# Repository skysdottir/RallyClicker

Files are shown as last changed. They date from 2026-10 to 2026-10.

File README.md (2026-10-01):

# A heltec t114-based sequence and time tracker for rally usage
## This is super prototype code, it seems to work but I make no guarantees.

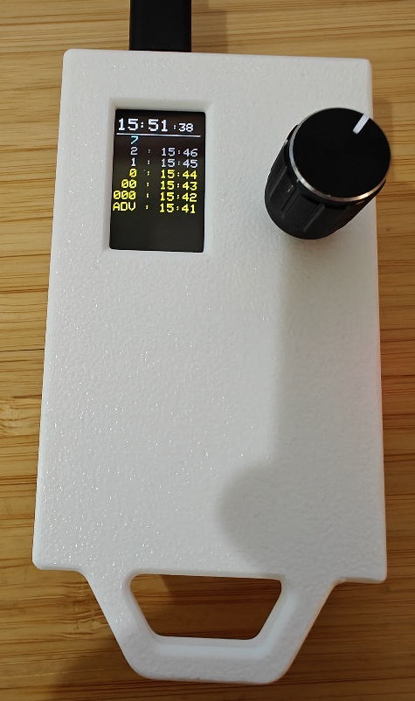
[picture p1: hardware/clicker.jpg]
A little device with a knob and screen. The screen displays time and log entries


## User Guide

The clicker display has two sections: a gps-synced real-time clock at the top and a log of button clicks below.

As is traditional with rally, the number seqence starts with the advance car, then 000, 00, and 0 before reaching sequence number 1. The teal number at the top of the log is the *next* sequence number, clicking will commit it and the current time to the log

When the clicker starts, the clock will be all red Xes and the knob will do nothing- this is normal while waiting for GPS.

Once GPS time is synced, the clock will update to real time (in the configured time zone), and the knob will begin to function:

**Clicking the knob** will record an entry to the log

**Twisting the knob** will scroll up or down the log. Clicking while scrolled down will still record to the top of the log, and scroll back up to the top - no need to worry about messing up the order

**Long-pressing the knob** will enter number-selection mode. The blue *next* number will blink

**While in number-selection-mode** twisting the knob will adjust the *next* number. Clicking or long-pressing the knob will return to log mode but not log an entry.

**Long-pressing the menu button** will enter the menu, for time zone adjustment

**Pressing the menu button again** will exit the menu

**The knob** will navigate and manipulate the menu. Click on an entry to adjust it, click again to back out to navigation.

*Note that this library currently only stores the log in memory - turning it off and then on again wil loose the current log!*

## Hardware needed
- Heltec T114
- Heltec GPS module (for time sync)
- Battery
  - 30mm x 40mm x 8mm
  - 1000mah
- Rotary encoder with click-button (for human input)
  - I used a generic KY-040 dev board
- MTS-101 mini toggle switch

## Wiring diagram

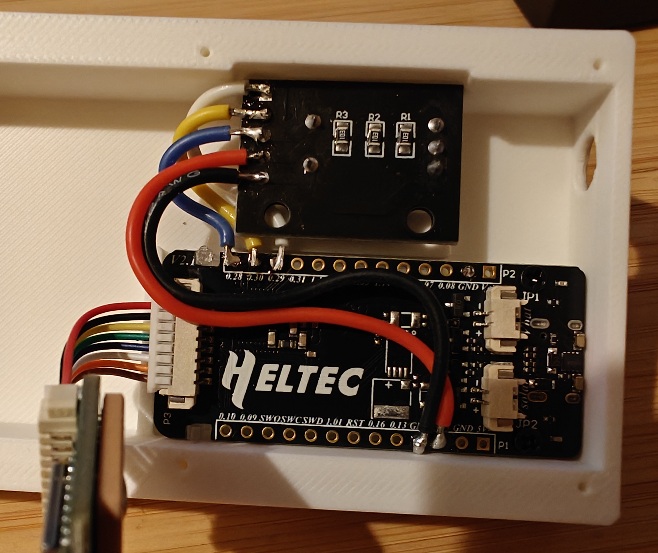
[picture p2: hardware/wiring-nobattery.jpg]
The interior of the device, with wiring displayed. The rotary encoder is connected to the T114


## Pin assignments

- **0.29** Rotary encoder CLK pin
- **0.30** Rotary encoder DT pin
- **0.28** Rotary encoder SW pin
  - (Yes, the IO pins are in this order on the board for some reason)

- **V3.3** Rotary encoder + pin
  - Might also work from Ve3.3, but haven't tried
- **G** Rotary encoder ground pin

## Software process

RallyClicker is a PlatformIO project, developed in VS Code. That'll be by far the easiest way to build, run, and flash the project.

In traditional arduino fashion, everything is mashed into main.cpp.

SPI TFTs are slow and drawing to the screen blocks encoder I/O: minimizing redraws is important.

## Acknowledgements

This project would not exist without the open source community

Graphics, filesystem, and neopixel libraries from Adafruit
Radio library (unused but needed for board) by Jan Gromeš
TinyGPSPlus library by Mikal Hart
AdvancedRotaryEncoder lib by Paul Thomsen 
Time library by Paul Stoffregen
Regexp library by Nick Gammon

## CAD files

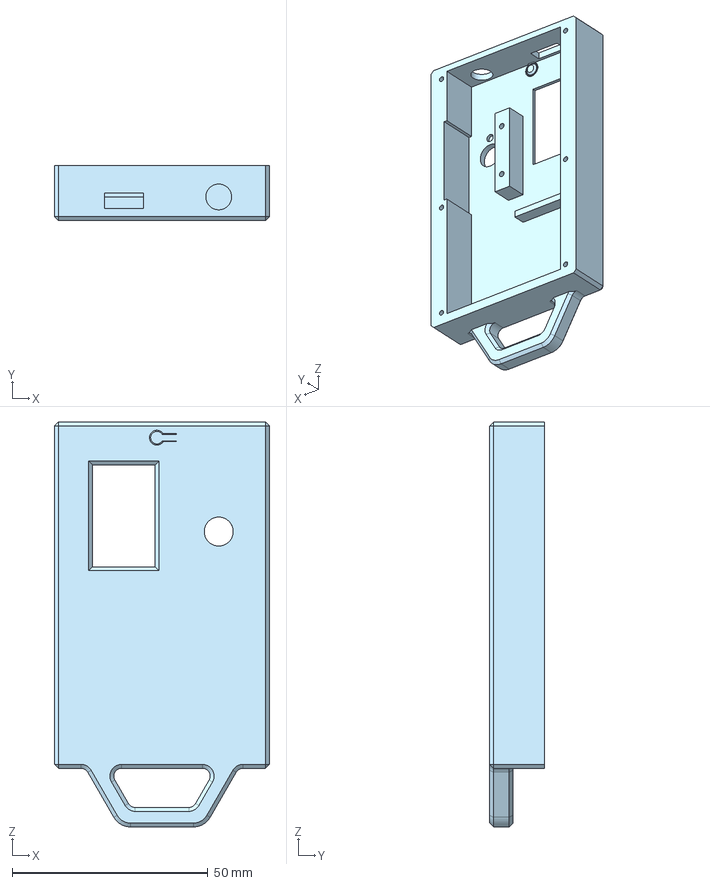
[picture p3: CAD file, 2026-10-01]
hardware/rally clicker - shell.step
55.0 x 14.0 x 103.5 mm

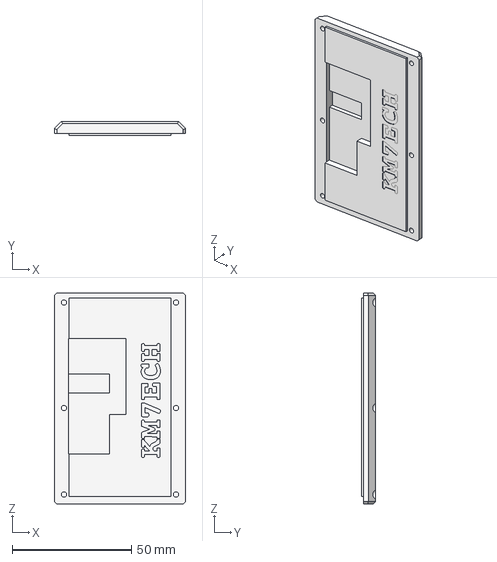
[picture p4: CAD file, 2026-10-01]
hardware/rally clicker - back.step
55.0 x 6.00 x 88.5 mm

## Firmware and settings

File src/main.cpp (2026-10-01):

#include <Adafruit_GFX.h>
#include <Adafruit_ST7789.h>
#include <Adafruit_LittleFS.h>
#include <InternalFileSystem.h>
#include <Arduino.h>
#include <TinyGPSPlus.h>
#include <TimeLib.h>
#include <Regexp.h>
#include <RotaryEncoder.h>

/* ADC */
#define SOC_GPIO_PIN_T114_ADC_EN 6 // P0.06

/* Ext. sensors */
#define SOC_GPIO_PIN_T114_VEXT_EN 21 // P0.21

/* TFT */
#define TFT_WIDTH  135
#define TFT_HEIGHT 240
#define SOC_GPIO_PIN_T114_TFT_MOSI  9 // P1.09
#define SOC_GPIO_PIN_T114_TFT_MISO  11 // P1.11 NC
#define SOC_GPIO_PIN_T114_TFT_SCK   8 // P1.08
#define SOC_GPIO_PIN_T114_TFT_SS    11 // P0.11
#define SOC_GPIO_PIN_T114_TFT_DC    12 // P0.12
#define SOC_GPIO_PIN_T114_TFT_RST   2 // P0.02
#define SOC_GPIO_PIN_T114_TFT_EN    3 // P0.03
#define SOC_GPIO_PIN_T114_TFT_BLGT  15 // P0.15

/* inputs */
#define CLICK_PIN 28
#define SCROLL_DIR_PIN 30
#define SCROLL_TRIGGER_PIN 29
#define MENU_BUTTON_PIN 42

/* GPS PPS pin - gotta get those micros*/
#define GPS_PPS_PIN 36

/* GPS */
#define GPSBAUD 9600

/* Battery status */
#define BATTERY_ADC_ACTIVATE_PIN 6
#define BATTERY_ADC_PIN 4
#define BATTERY_TOTAL_RESIST 490.0
#define BATTERY_LOWER_RESIST 100.0

/* File system */
#define CONFIG_FILE_NAME "/rallyclickconfig.txt"
#define LOG_FILE_NAME "/rallyclicklog.txt"

/* Magic numbers */
#define BUF_SIZE 1024 // An event is never going to have more than 1024 cars, right?

// don't do this
#define TIME_ZONE_COUNT 38
int timezones[] = {-1200, -1100, -1000, -930, -900, -800, -700, -600, -500, -400, -330, -300, -200, -100, 0, 100, 200, 300, 330, 400, 430, 500, 530, 545, 600, 630, 700, 800, 845, 900, 930, 1000, 1030, 1100, 1200, 1245, 1300, 1400};
int timezone = -700;
int time_zone_index = 6;

TinyGPSPlus gps;
Adafruit_ST7789 tft(&SPI1, SOC_GPIO_PIN_T114_TFT_SS, SOC_GPIO_PIN_T114_TFT_DC, SOC_GPIO_PIN_T114_TFT_RST);
RotaryEncoder encoder(SCROLL_TRIGGER_PIN, SCROLL_DIR_PIN, CLICK_PIN);

// GPS ISR flags
volatile bool proc_time_sync = false;  // T when gps pps pulse arrives, F on next loop()
volatile bool next_second = false;     // T when gps pps pulse arrives, F when gps serial second advances

// main state switches
bool time_sync_good = false;
bool editing_carnum = false;
bool in_menu = false;
bool editing_menu_item = false;
bool just_toggled_menu_state = true;
bool config_changed = false;
bool checking_battery = false;

int nextcar = -3; // -3: ADV  -2: 000  -1: 00
int logged = 0;
int scroll_offset = 0;

int battery_percent = 0;

// Menu button debounce
long last_menu_off = 0;
int menu_index = 0;
#define MENU_ITEM_COUNT 1

// the in-memory log store
int cars[BUF_SIZE];
long times[BUF_SIZE];

int lasthr = -1;
int lastmin = -1;
int lastsec = -1;

// fortunately we only care about hours and minutes. Days can be wrong, they aren't displayed
time_t toTimeZone(time_t t) {
    unsigned long magic = (unsigned long) t;
    magic += (timezone % 100) * 60;
    magic += (timezone / 100) * 3600;
    return (time_t) magic;
}

void displayTime() {
    tft.setTextSize(3); // set text size
    tft.setCursor(0, 0); // set cursor position
    
    // font size 1: 6x8, 1 px padding right and bottom
    // font size 2: 12x16, 2 px padding
    // font size 3: 18x24, 3 px padding

    if (time_sync_good) {

        // now() should return UTC time
        time_t t = toTimeZone(now());

        int t_hour = hour(t);
        int t_minute = minute(t);
        int t_second = second(t);

        tft.setTextColor(ST77XX_WHITE, ST77XX_BLACK);

        if (lasthr != t_hour) {
            tft.printf("%02d", t_hour);
            lasthr = t_hour;
        }

        if (lastmin != t_minute) {
            tft.setCursor(33, 0);
            tft.printf(":%02d", t_minute);
            lastmin = t_minute;
        }

        if (lastsec != t_second) {
            tft.setTextSize(2);
            tft.setCursor(88, 6);
            tft.printf(":%02d", t_second);
            lastsec = t_second;
        }
        
    } else {
        tft.setTextColor(ST77XX_RED, ST77XX_BLACK);
        tft.print("XX:XX");
        tft.setTextSize(2);
        tft.setCursor(tft.getCursorX(), 6);
        tft.print(":XX");
    }
}

void displayCarnum(int idx, int num, int y) {
    tft.setTextSize(2);

    if (idx == -1) {
        if (editing_carnum && millis() % 1000 < 500) {
            tft.setTextColor(0x4208, ST77XX_BLACK);
        } else {
            tft.setTextColor(ST77XX_CYAN, ST77XX_BLACK);
        }
    } else if (num < 1) {
        tft.setTextColor(ST77XX_YELLOW, ST77XX_BLACK);
    } else if (idx == 0 && scroll_offset == 0) {
        tft.setTextColor(ST77XX_WHITE, ST77XX_BLACK);
    } else {
        tft.setTextColor(0xBDD7, ST77XX_BLACK);
    }
    tft.setCursor(0, y);

    switch(num) {
        case -3:
        tft.print("ADV");
        break;
        case -2:
        tft.print("000");
        break;
        case -1:
        tft.print(" 00");
        break;
        default:
        tft.printf("%3d", num);
    }
}

void displayEntry(int draw_idx) {
    int y = 52 + draw_idx*20;
    
    int buf_idx = (logged - draw_idx - scroll_offset - 1);
    
    if (buf_idx < 0) {
        // blank this row
        tft.setTextColor(ST77XX_BLACK, ST77XX_BLACK);
        tft.setCursor(0, y);
        for (int i = 0; i < 11; i++) {
            tft.print((char) 0xDA);
        }
        return;
    }

    buf_idx %= BUF_SIZE;

    int seqnum = cars[buf_idx];

    displayCarnum(draw_idx, seqnum, y);

    // Stored in UTC, display in current time zone
    time_t zoned_t = toTimeZone(times[buf_idx]);

    if (seqnum > 999) {
        tft.printf(": %02d:%02d", hour(zoned_t), minute(zoned_t));
    } else {
        tft.printf(" : %02d:%02d", hour(zoned_t), minute(zoned_t));
    }
}

void displayWaitingForGps() {
    tft.drawLine(0, 28, 135, 28, ST77XX_WHITE);
    tft.setTextColor(ST77XX_WHITE, ST77XX_BLACK);
    tft.setTextSize(2);
    tft.setCursor(28, 52);
    tft.print("waiting");
    tft.setCursor(44, 72);
    tft.print("for");
    tft.setCursor(44, 92);
    tft.print("GPS");
    tft.setCursor(40, 112);
    tft.print("time");
    tft.setCursor(40, 132);
    tft.print("sync");
}

void clearLog() {
    tft.drawLine(0, 28, 135, 28, ST77XX_WHITE);
    tft.fillRect(0, 29, 135, 240, ST77XX_BLACK);
}

void displayNextCar() {
    tft.drawLine(0, 28, 135, 28, ST77XX_WHITE);
    displayCarnum(-1, nextcar, 32);
}

void displayLog() {
    tft.setTextSize(2);

    // draw the log. 10 here is the number of lines to display.
    for(int i = 0; (i < 10); i++) {
        displayEntry(i);
    }
}

void displayMenuItem(int index) {
    int first_row_y = 52 + index*40;
    int second_row_y = 52 + index*40 + 20;

    int first_row_fg_color = 0xBDD7;
    int second_row_fg_color = 0xBDD7;
    int bg_color = ST77XX_BLACK;

    // this is the active item
    if (index == menu_index) {
        if (editing_menu_item) {
            first_row_fg_color = ST77XX_CYAN;
            if (millis() % 1000 < 500) {
                second_row_fg_color = ST77XX_CYAN;
            } else {
                second_row_fg_color = 0xBDD7;
            }
        } else {
            first_row_fg_color = ST77XX_WHITE;
            second_row_fg_color = ST77XX_WHITE;
        }
        
        bg_color = 0x4208;
    }

    tft.setTextSize(2);
    tft.setTextColor(first_row_fg_color, bg_color);
    tft.setCursor(0, first_row_y);
    switch(index) {
        case 0:
            tft.print("time zone");
            break;
        case 1:
            tft.print("exit menu");
            break;
        default: break;
    }

    tft.setTextColor(second_row_fg_color, bg_color);
    tft.setCursor(0, second_row_y);

    int pretty_minutes = timezone%100;
    if (pretty_minutes < 0) {
            pretty_minutes *= -1;
    }

    switch(index) {
        case 0: 
            tft.print("UTC");
            tft.printf("%+03d:%02d", timezone/100, pretty_minutes);
            break;
        default: break;
    }
}

void displayMenu() {
    tft.drawLine(0, 28, 135, 28, ST77XX_WHITE);
    for (int i = 0; i <= MENU_ITEM_COUNT; i++) {
        displayMenuItem(i);
    }
}

void incrementMenuItem(int dir) {
    switch(menu_index) {
        case 0: // time zone
            if (dir < 0 && time_zone_index > 0) {
                time_zone_index--;
                timezone = timezones[time_zone_index];
            } else if (dir > 0 && time_zone_index < TIME_ZONE_COUNT - 1) {
                time_zone_index++;
                timezone = timezones[time_zone_index];
            }
            config_changed = true;
        case 1: break; // can't scroll the exit button
        default: break;
    }
}

void displayBattery() {
    int battery_color = ST77XX_GREEN;
    if (battery_percent < 20) {
        battery_color = ST77XX_RED;
    } else if (battery_percent < 40) {
        battery_color = ST77XX_YELLOW;
    }

    int battery_start_y = 20 - (battery_percent * 20) / 100;

    tft.fillRect(128, 0, 6, battery_start_y, ST77XX_BLACK);
    tft.fillRect(128, battery_start_y, 6, 24-battery_start_y, battery_color);
}

void parseConfigFile() {
    Adafruit_LittleFS_Namespace::File cfg(InternalFS);
    char cfg_buf[1024];

    if(InternalFS.exists(CONFIG_FILE_NAME)) {
        cfg.open(CONFIG_FILE_NAME, Adafruit_LittleFS_Namespace::FILE_O_READ);
        if (cfg) {
            while(cfg.available()) {
                String config_line = cfg.readStringUntil('\n');
                config_line.toCharArray(cfg_buf, 1024);
                MatchState match(cfg_buf);

                char result = match.Match("^timezone_index=(%d+)$");

                if(result == REGEXP_MATCHED) {
                    char cfg_timezone_index_str[4];
                    match.GetCapture(cfg_timezone_index_str, 0);
                    int cfg_timezone_index = atoi(cfg_timezone_index_str);

                    if(cfg_timezone_index >= 0 && cfg_timezone_index < TIME_ZONE_COUNT) {
                        time_zone_index = cfg_timezone_index;
                        timezone = timezones[time_zone_index];
                    }
                }
            }
            cfg.close();
        }
    }
}

void saveConfig() {
    if (config_changed) {
        Adafruit_LittleFS_Namespace::File cfg(InternalFS);

        if (InternalFS.exists(CONFIG_FILE_NAME)) {
            InternalFS.remove(CONFIG_FILE_NAME);
        }

        cfg.open(CONFIG_FILE_NAME, Adafruit_LittleFS_Namespace::FILE_O_WRITE);

        if(cfg) {
            cfg.printf("timezone_index=%d\n", time_zone_index);
        }

        cfg.close();
    }
}

void onGpsPPS() {
    proc_time_sync = true;
    next_second = true;
}

void setup(void) {

    // enable vext (not required for screen to work, but probably for antenna boost?)
    pinMode(SOC_GPIO_PIN_T114_VEXT_EN, OUTPUT);
    digitalWrite(SOC_GPIO_PIN_T114_VEXT_EN, HIGH);

    delay(100); // Give power time to stabilize

    // enable power to display
    digitalWrite(SOC_GPIO_PIN_T114_TFT_EN, LOW);
    pinMode(SOC_GPIO_PIN_T114_TFT_EN, OUTPUT);

    // enable backlight led (display is off without this)
    digitalWrite(SOC_GPIO_PIN_T114_TFT_BLGT, LOW);
    pinMode(SOC_GPIO_PIN_T114_TFT_BLGT, OUTPUT);

    // enable adc (not required for screen to work, but probably for measuring battery level)
    digitalWrite(SOC_GPIO_PIN_T114_ADC_EN, HIGH);
    pinMode(SOC_GPIO_PIN_T114_ADC_EN, OUTPUT);

    Serial.begin(115200);
    Serial.println("init");
    Serial2.begin(GPSBAUD);

    // init tft
    tft.init(TFT_WIDTH, TFT_HEIGHT);
    tft.setRotation(2);
    tft.setSPISpeed(40000000);

    // show something on the display
    tft.fillScreen(ST77XX_BLACK); // clear the screen
    tft.setTextColor(ST77XX_WHITE); // set text color to white
    tft.setTextSize(2); // set text size
    tft.setCursor(0, 0); // set cursor position
    tft.print("Booting...");

    encoder.setRepeatTiming(200, 60);
    encoder.useInternalPullups(false);
    encoder.enableInterrupts();
    encoder.enableLongPress(1500);
    encoder.begin(false);
    
    InternalFS.begin();
    parseConfigFile();

    pinMode(GPS_PPS_PIN, INPUT_PULLDOWN);
    attachInterrupt(digitalPinToInterrupt(GPS_PPS_PIN), onGpsPPS, RISING);

    pinMode(MENU_BUTTON_PIN, INPUT);
    last_menu_off = millis();

    pinMode(BATTERY_ADC_ACTIVATE_PIN, OUTPUT);
    digitalWrite(BATTERY_ADC_ACTIVATE_PIN, 1);
    checking_battery = true;
    pinMode(BATTERY_ADC_PIN, INPUT);

    displayTime();
    displayWaitingForGps();
}

long gps_lastbit = 0;
long gps_lastframe = 0;
long last_gps_second = -1; // tracks the second we're seeing in serial messages from GPS

void loop() {
    bool proc_time_redraw = false;
    bool proc_next_car_redraw = false;
    bool proc_log_redraw = false;
    bool proc_log_clear = false;
    bool proc_menu_redraw = false;
    bool proc_menu_item_redraw = false;
    bool proc_battery_gauge_redraw = false;

    long t = millis();

    // update the last menu button time immediately
    if (digitalRead(MENU_BUTTON_PIN)) {
        last_menu_off = t;
        just_toggled_menu_state = false;
    }

    while(Serial2.available() > 0) {
        int buf = Serial2.read();
        if(gps.encode(buf)) {
            gps_lastframe = t;
        }
        gps_lastbit = t;
    }

    if(checking_battery) {
        int batt_raw = analogRead(BATTERY_ADC_PIN);
        double batt_volts = (batt_raw * BATTERY_TOTAL_RESIST * 3.3) / (BATTERY_LOWER_RESIST * 1024);
        battery_percent = (int) ((batt_volts - 3.3) * 100 / 0.7);
        if (battery_percent < 0) {
            battery_percent = 0;
        }
        if (battery_percent > 100) {
            battery_percent = 100;
        }

        proc_battery_gauge_redraw = true;
        digitalWrite(BATTERY_ADC_ACTIVATE_PIN, 0);
        checking_battery = false;
    }

    // battery check once a minute
    if(proc_time_sync && second() == 10) {
        digitalWrite(BATTERY_ADC_ACTIVATE_PIN, 1);
        checking_battery = true;
        // and then we wait for the next loop to check the adc
    }

    if (gps.time.isValid() && (gps.date.year() > 2020)) {
        // we've got datetime!
        
        int serial_secs = gps.time.second();

        if (serial_secs != last_gps_second) {
            // if the serial seconds have advanced, great, we no longer need to add 1.
            next_second = false;
            last_gps_second = serial_secs;
        }

        int real_secs = (next_second) ? serial_secs + 1 : serial_secs;

        proc_time_redraw = (real_secs != lastsec);

        if (!time_sync_good || (proc_time_sync && real_secs == 30)) {
            // either we haven't initted our time
            // or this is the first loop of the 30th second of the minute

            // set time in UTC, as it should be
            setTime(gps.time.hour(), 
                    gps.time.minute(), 
                    real_secs, 
                    gps.date.day(), 
                    gps.date.month(), 
                    gps.date.year());

            proc_time_redraw = true;
            if (!time_sync_good && !in_menu) {
                proc_log_clear = true;
                proc_next_car_redraw = true;
            }

            time_sync_good = true;
        }

        proc_time_sync = false;
    }

    // now the IO stuff

    // menu button - long press to enter, short press to exit
    if (!in_menu && !just_toggled_menu_state && (t - last_menu_off > 1500)) {
        in_menu = true;
        editing_menu_item = false;
        editing_carnum = false;
        menu_index = 0;
        proc_log_clear = true;
        proc_menu_redraw = true;
        just_toggled_menu_state = true;
    } else if (in_menu && !just_toggled_menu_state && (t - last_menu_off > 50)) {
        saveConfig();
        in_menu = false;
        editing_menu_item = false;
        proc_log_clear = true;
        just_toggled_menu_state = true;
        proc_next_car_redraw = true;
        proc_log_redraw = true;
    }

    encoder.update();
    int delta = encoder.read();

    if (delta > 0) {
        if (editing_carnum) {
            nextcar++;
            proc_next_car_redraw = true;
        }else if (in_menu) {
            if (editing_menu_item) {
                incrementMenuItem(1);
                proc_menu_item_redraw = true;
            } else if (menu_index < MENU_ITEM_COUNT) {
                menu_index++;
                proc_menu_redraw = true;
            }
        } else if (scroll_offset > 0) {
            scroll_offset--;
            proc_log_redraw = true;
        }
    }

    if (delta < 0) {
        if (editing_carnum && nextcar > -3) {
            nextcar--;
            proc_next_car_redraw = true;
        } else if (in_menu) {
            if (editing_menu_item) {
                incrementMenuItem(-1);
                proc_menu_item_redraw = true;
            } else if (menu_index > 0) {
                menu_index--;
                proc_menu_redraw = true;
            }
        }else if (scroll_offset < logged-5) {
        scroll_offset++;
        proc_log_redraw = true;
        }
    }

    if (encoder.click() ) {
        if (in_menu) {
            if (menu_index == MENU_ITEM_COUNT) {
                // quit is always the last option
                saveConfig();
                in_menu = false;
                proc_log_clear = true;
                proc_next_car_redraw = true;
                proc_log_redraw = true;
            } else {
                editing_menu_item = !editing_menu_item;
                proc_menu_redraw = true;
            }
        } else if (editing_carnum) {
            editing_carnum = false;
            proc_next_car_redraw = true;
        } else if (time_sync_good) {
            long t = now();
            int index = logged % BUF_SIZE;
            cars[index] = nextcar;
            times[index] = t;
            logged++;
            nextcar++;
            scroll_offset = 0;
            proc_next_car_redraw = true;
            proc_log_redraw = true;
        }
    }

    if (encoder.longPress() && !in_menu && time_sync_good) {
        editing_carnum = !editing_carnum;
        proc_next_car_redraw = true;
    }

    if(proc_time_redraw) {
        displayTime();
    }

    // blinky
    if(millis() % 500 < 20) {
        if(!in_menu && editing_carnum) {
            proc_next_car_redraw = true;
        } else if (in_menu && editing_menu_item) {
            proc_menu_item_redraw = true;
        }
    }

    if (proc_log_clear) {
        clearLog();
    }

    if (time_sync_good) {
        if (proc_next_car_redraw) {
            displayNextCar();
        }

        if (proc_log_redraw) {
            displayLog();
        } 
    } else if (proc_next_car_redraw || proc_log_redraw) {
        displayWaitingForGps();
    }

    if (proc_menu_redraw) {
        displayMenu();
    }

    if (proc_menu_item_redraw) {
        displayMenuItem(menu_index);
    }

    if (proc_battery_gauge_redraw) {
        displayBattery();
    }

    delay(10);
}

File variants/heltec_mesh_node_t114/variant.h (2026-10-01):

/*
 Copyright (c) 2014-2015 Arduino LLC.  All right reserved.
 Copyright (c) 2016 Sandeep Mistry All right reserved.
 Copyright (c) 2018, Adafruit Industries (adafruit.com)

 This library is free software; you can redistribute it and/or
 modify it under the terms of the GNU Lesser General Public
 License as published by the Free Software Foundation; either
 version 2.1 of the License, or (at your option) any later version.
 This library is distributed in the hope that it will be useful,
 but WITHOUT ANY WARRANTY; without even the implied warranty of
 MERCHANTABILITY or FITNESS FOR A PARTICULAR PURPOSE.
 See the GNU Lesser General Public License for more details.
 You should have received a copy of the GNU Lesser General Public
 License along with this library; if not, write to the Free Software
 Foundation, Inc., 51 Franklin St, Fifth Floor, Boston, MA  02110-1301  USA
*/

#ifndef _VARIANT_HELTEC_NRF_
#define _VARIANT_HELTEC_NRF_
/** Master clock frequency */
#define VARIANT_MCK (64000000ul)

#define USE_LFXO // Board uses 32khz crystal for LF

/*----------------------------------------------------------------------------
 *        Headers
 *----------------------------------------------------------------------------*/

#include "WVariant.h"

#ifdef __cplusplus
extern "C" {
#endif // __cplusplus

#define HELTEC_MESH_NODE_T114

#define USE_ST7789

#define ST7789_NSS 11
#define ST7789_RS 12  // DC
#define ST7789_SDA 41 // MOSI
#define ST7789_SCK 40
#define ST7789_RESET 2
#define ST7789_MISO -1
#define ST7789_BUSY -1
#define VTFT_CTRL 3
#define VTFT_LEDA 15
// #define ST7789_BL (32+6)
#define TFT_BACKLIGHT_ON LOW
#define ST7789_SPI_HOST SPI1_HOST
// #define TFT_BL (32+6)
#define SPI_FREQUENCY 40000000
#define SPI_READ_FREQUENCY 16000000
#define TFT_HEIGHT 135
#define TFT_WIDTH 240
#define TFT_OFFSET_X 0
#define TFT_OFFSET_Y 0

// #define TFT_OFFSET_ROTATION 0
// #define SCREEN_ROTATE
// #define SCREEN_TRANSITION_FRAMERATE 5

// Number of pins defined in PinDescription array
#define PINS_COUNT (48)
#define NUM_DIGITAL_PINS (48)
#define NUM_ANALOG_INPUTS (1)
#define NUM_ANALOG_OUTPUTS (0)

// LEDs
#define PIN_LED1 (32 + 3) // green (confirmed on 1.0 board)
#define LED_BLUE PIN_LED1 // fake for bluefruit library
#define LED_GREEN PIN_LED1
#define LED_STATE_ON 0 // State when LED is lit

#define HAS_NEOPIXEL                         // Enable the use of neopixels
#define NEOPIXEL_COUNT 2                     // How many neopixels are connected
#define NEOPIXEL_DATA 14                     // gpio pin used to send data to the neopixels
#define NEOPIXEL_TYPE (NEO_GRB + NEO_KHZ800) // type of neopixels in use

/*
 * Buttons
 */
#define PIN_BUTTON1 (32 + 10)
// #define PIN_BUTTON2 (0 + 18)      // 0.18 is labeled on the board as RESET but we configure it in the bootloader as a regular
// GPIO

/*
No longer populated on PCB
*/
#define PIN_SERIAL2_RX (32 + 5)
#define PIN_SERIAL2_TX (32 + 7)
//  #define PIN_SERIAL2_EN (0 + 17)

/*
 * I2C
 */

#define WIRE_INTERFACES_COUNT 2

// I2C bus 0
// Routed to footprint for PCF8563TS RTC
// Not populated on T114 V1, maybe in future?
#define PIN_WIRE_SDA (0 + 26) // P0.26
#define PIN_WIRE_SCL (0 + 27) // P0.27

// I2C bus 1
// Available on header pins, for general use
#define PIN_WIRE1_SDA (0 + 16) // P0.16
#define PIN_WIRE1_SCL (0 + 13) // P0.13

// QSPI Pins
#define PIN_QSPI_SCK (32 + 14)
#define PIN_QSPI_CS (32 + 15)
#define PIN_QSPI_IO0 (32 + 12) // MOSI if using two bit interface
#define PIN_QSPI_IO1 (32 + 13) // MISO if using two bit interface
#define PIN_QSPI_IO2 (0 + 7)   // WP if using two bit interface (i.e. not used)
#define PIN_QSPI_IO3 (0 + 5)   // HOLD if using two bit interface (i.e. not used)

// On-board QSPI Flash
#define EXTERNAL_FLASH_DEVICES MX25R1635F
#define EXTERNAL_FLASH_USE_QSPI

/*
 * Lora radio
 */

#define USE_SX1262
// #define USE_SX1268
#define SX126X_CS (0 + 24) // FIXME - we really should define LORA_CS instead
#define LORA_CS (0 + 24)
#define SX126X_DIO1 (0 + 20)
// Note DIO2 is attached internally to the module to an analog switch for TX/RX switching
// #define SX1262_DIO3 (0 + 21)
// This is used as an *output* from the sx1262 and connected internally to power the tcxo, do not drive from the
//    main
// CPU?
#define SX126X_BUSY (0 + 17)
#define SX126X_RESET (0 + 25)
// Not really an E22 but TTGO seems to be trying to clone that
#define SX126X_DIO2_AS_RF_SWITCH
#define SX126X_DIO3_TCXO_VOLTAGE 1.8

#define PIN_SPI1_MISO                                                                                                            \
    ST7789_MISO // FIXME not really needed, but for now the SPI code requires something to be defined, pick an used GPIO
#define PIN_SPI1_MOSI ST7789_SDA
#define PIN_SPI1_SCK ST7789_SCK

/*
 * Bluetooth
 */

// The bluetooth transmit power on the nRF52840 is adjustable from -20dB to +8dB in steps of 4dB
// so NRF52_BLE_TX_POWER can be set to -20, -16, -12, -8, -4, 0 (default), 4, and 8.
// #define NRF52_BLE_TX_POWER 8

/*
 * GPS pins
 */

#define GPS_L76K

// #define PIN_GPS_RESET (32 + 6) // An output to reset L76K GPS. As per datasheet, low for > 100ms will reset the L76K
#define GPS_RESET_MODE LOW
// #define PIN_GPS_EN (21)
#define VEXT_ENABLE (0 + 21)
#define PERIPHERAL_WARMUP_MS 1000 // Make sure I2C QuickLink has stable power before continuing
#define VEXT_ON_VALUE HIGH
// #define GPS_EN_ACTIVE HIGH
#define PIN_GPS_STANDBY (32 + 2) // An output to wake GPS, low means allow sleep, high means force wake
#define PIN_GPS_PPS (32 + 4)
// Seems to be missing on this new board
// #define PIN_GPS_PPS (32 + 4)  // Pulse per second input from the GPS
#define GPS_TX_PIN (32 + 7) // This is for bits going TOWARDS the CPU
#define GPS_RX_PIN (32 + 5) // This is for bits going TOWARDS the GPS

#define GPS_THREAD_INTERVAL 50

#define PIN_SERIAL1_RX GPS_RX_PIN
#define PIN_SERIAL1_TX GPS_TX_PIN

/*
 * SPI Interfaces
 */
#define SPI_INTERFACES_COUNT 2

// For LORA, spi 0
#define PIN_SPI_MISO (0 + 23)
#define PIN_SPI_MOSI (0 + 22)
#define PIN_SPI_SCK (0 + 19)

// To debug via the segger JLINK console rather than the CDC-ACM serial device
// #define USE_SEGGER

// Battery
// The battery sense is hooked to pin A0 (4)
// it is defined in the anlaolgue pin section of this file
// and has 12 bit resolution

#define ADC_CTRL 6
#define ADC_CTRL_ENABLED HIGH
#define BATTERY_PIN 4
#define ADC_RESOLUTION 14

#define BATTERY_SENSE_RESOLUTION_BITS 12
#define BATTERY_SENSE_RESOLUTION 4096.0
#undef AREF_VOLTAGE
#define AREF_VOLTAGE 3.0
#define VBAT_AR_INTERNAL AR_INTERNAL_3_0
#define ADC_MULTIPLIER (4.916F)

// rf52840 AIN2 = Pin 4
// commented out due to power leakage of 2.9mA in shutdown state see reported issue #8801
// #define BATTERY_LPCOMP_INPUT NRF_LPCOMP_INPUT_2 //UNSAFE
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

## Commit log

2026-10-01 V1 (works?)
    Just copy-paste it to a new repo and cross the fingers. It's fine.
2026-10-01 Expanded readme, added case step files
    [rally clicker - back.step, rally clicker - shell.step]
2026-10-01 added print-in-place menu button to shell
    Added print-in-place button for menu
    [rally clicker - shell.step]
2026-10-01 use printf more
    ...and also handle four-digit sequence numbers gracefully. Is that ever going to be used? Probably not
2026-10-01 battery level monitor
    very simple, just lerping between high and low voltages on the voltage divider
2026-10-01 fixed battery gauge
